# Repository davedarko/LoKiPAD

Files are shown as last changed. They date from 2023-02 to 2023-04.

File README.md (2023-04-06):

# LoKiPAD
A low cost adafruit [macropad](https://learn.adafruit.com/adafruit-macropad-rp2040/) clone with integrated todbot [MacroPadSynthPlug!](https://github.com/todbot/macropadsynthplug) Partslist is kept minimal and some things like the SD-card adapter, debug LED and speaker were dropped. Generic 12mm SMD buttons, 3535 WS2812B LEDs, an OLED module and a Raspberry PI Pico keep the price low. Check the ibom file for more info on the resistor and capacitor values. There's a small hack necessary so you don't have to remove the PCB from the case to push the BOOTSEL button - connect the pad with a jumper wire to a pin of the pico bootsel button.

## Code
Chose the Adafruit MacroPad RP2040 to compile the Arduino examples from todbot, so the SPI pins for the display are setup correctly. You also have to (re)define some pins to make the oled display and the LEDs work. There might be an issue with the encoder - if it feels backwards, just swap the PIN_ROTA and PIN_ROTB definition.

Since this is hardware to run todbots code, there's no code of my own to find here.

```c
#define PIN_NEOPIXEL 19
#define PIN_ROTA 18
#define PIN_ROTB 17
#define OLED_DC  14
#define OLED_RST 15
#define OLED_CS  22
```
## code of other people
This [MIDI controller code](https://gist.github.com/codeandmake/a2a5672fd49b748823cb352ba72d804a) by @codeandmake works great too, once you've changed the pin definition. 
---

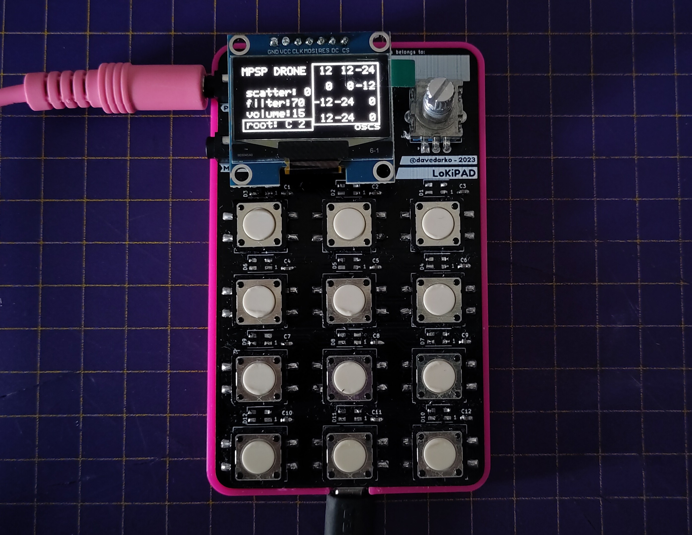
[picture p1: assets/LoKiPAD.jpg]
Picture of a 12 button macropad with an OLED and a encoder knob


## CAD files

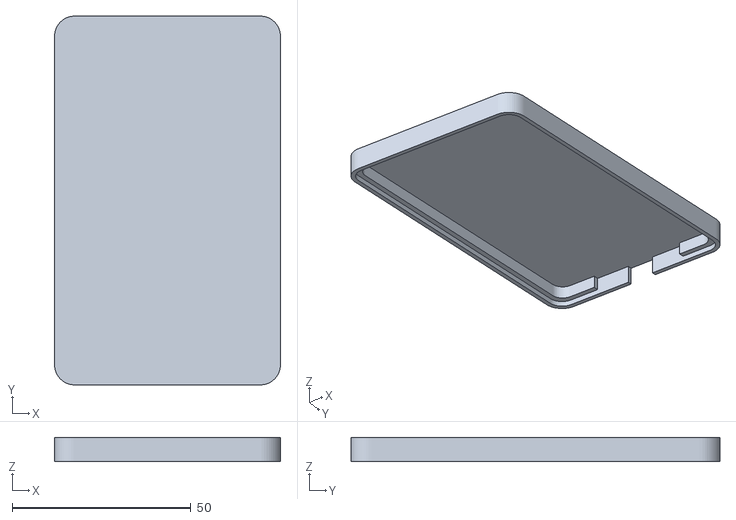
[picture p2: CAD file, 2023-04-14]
Case/LoKiPADcase.stl
63.3 x 103.3 x 6.75

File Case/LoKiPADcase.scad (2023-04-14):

use <rounded_box.scad>

$fn=50;

w=60;
d=100;
h=1.6;
r=4;

o=.3;
t=0.45*3;
th=7;
i=2.54;

screwHoles = false;
difference() {
	
	union () {
		
		rd = 2.5;
		if (screwHoles) {
			translate([-w/2+i,d/2-i,h]) cylinder(th-h-h+t, rd, rd);	
			translate([+w/2-i,d/2-i,h]) cylinder(th-h-h+t, rd, rd);
		}

		difference() {
		
		
			rounded_box(o+o+w+t+t,o+o+d+t+t,th-h+t,r+o+t);
			

			// first stage pcb rim
			translate([0,0,-1])
			rounded_box(w+o+o,d+o+o,h+1,r+o);
			
			// second stage holding corner
			translate([0,0,-1])
			rounded_box(w-t-t,d-t-t,th-h+1,r-o);

		 // color("black") rounded_box(w,d,h,r);
		
		}
	}
	
	if(screwHoles) {
		translate([-w/2+i,d/2-i,0]) cylinder(th-t, 1, 1);
		translate([+w/2-i,d/2-i,0]) cylinder(th-t, 1, 1);
	}
	
	usbSocket();



}

if($preview) {
	color("black", 0.5)
	rounded_box(w,d,h,r);
}

if($preview) usbSocket();

module usbSocket() {
	usb = 9;
	color("red", 0.2)
	translate([-usb/2,d/2-usb/2,-usb+th-h])
	cube(usb);
	
	usb2 = 32;
	color("red", 0.2)
	translate([-usb2/2,d/2-usb2+o,-usb2+th-h])
	cube(usb2);
	
}

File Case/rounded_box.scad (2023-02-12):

module rounded_box(w,d,h,r)
{
	union(){
		translate([-w/2+r, -d/2+r, 0]) cylinder(h, r, r);
		translate([-w/2+r, d/2-r, 0]) cylinder(h, r, r);
		translate([w/2-r, -d/2+r, 0]) cylinder(h, r, r);
		translate([w/2-r, d/2-r, 0]) cylinder(h, r, r);
		
		translate([-w/2+r, -d/2, 0]) cube([w-r*2,d,h]);
		translate([-w/2, -d/2+r, 0]) cube([w,d-r*2,h]);
	}
}

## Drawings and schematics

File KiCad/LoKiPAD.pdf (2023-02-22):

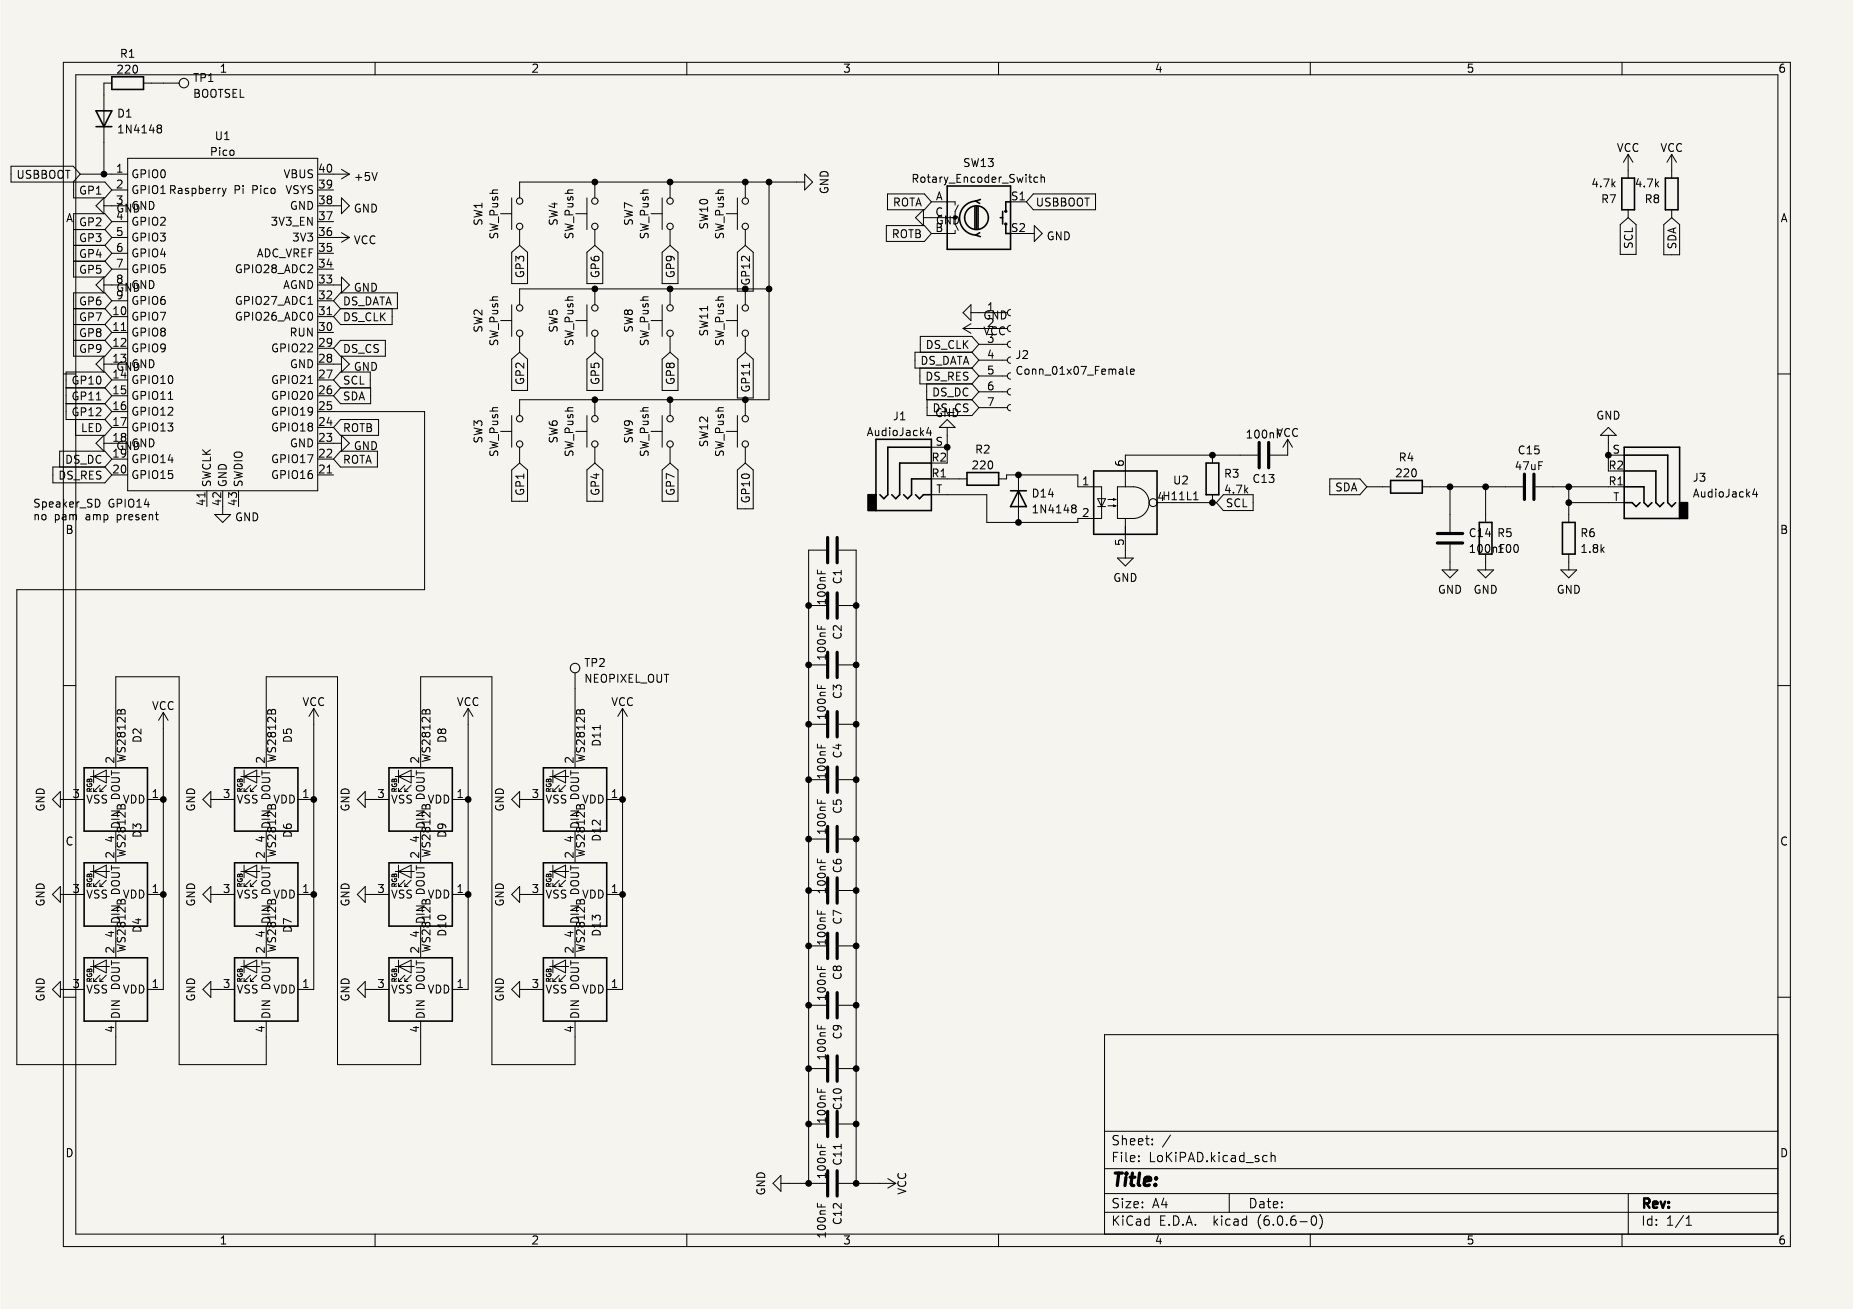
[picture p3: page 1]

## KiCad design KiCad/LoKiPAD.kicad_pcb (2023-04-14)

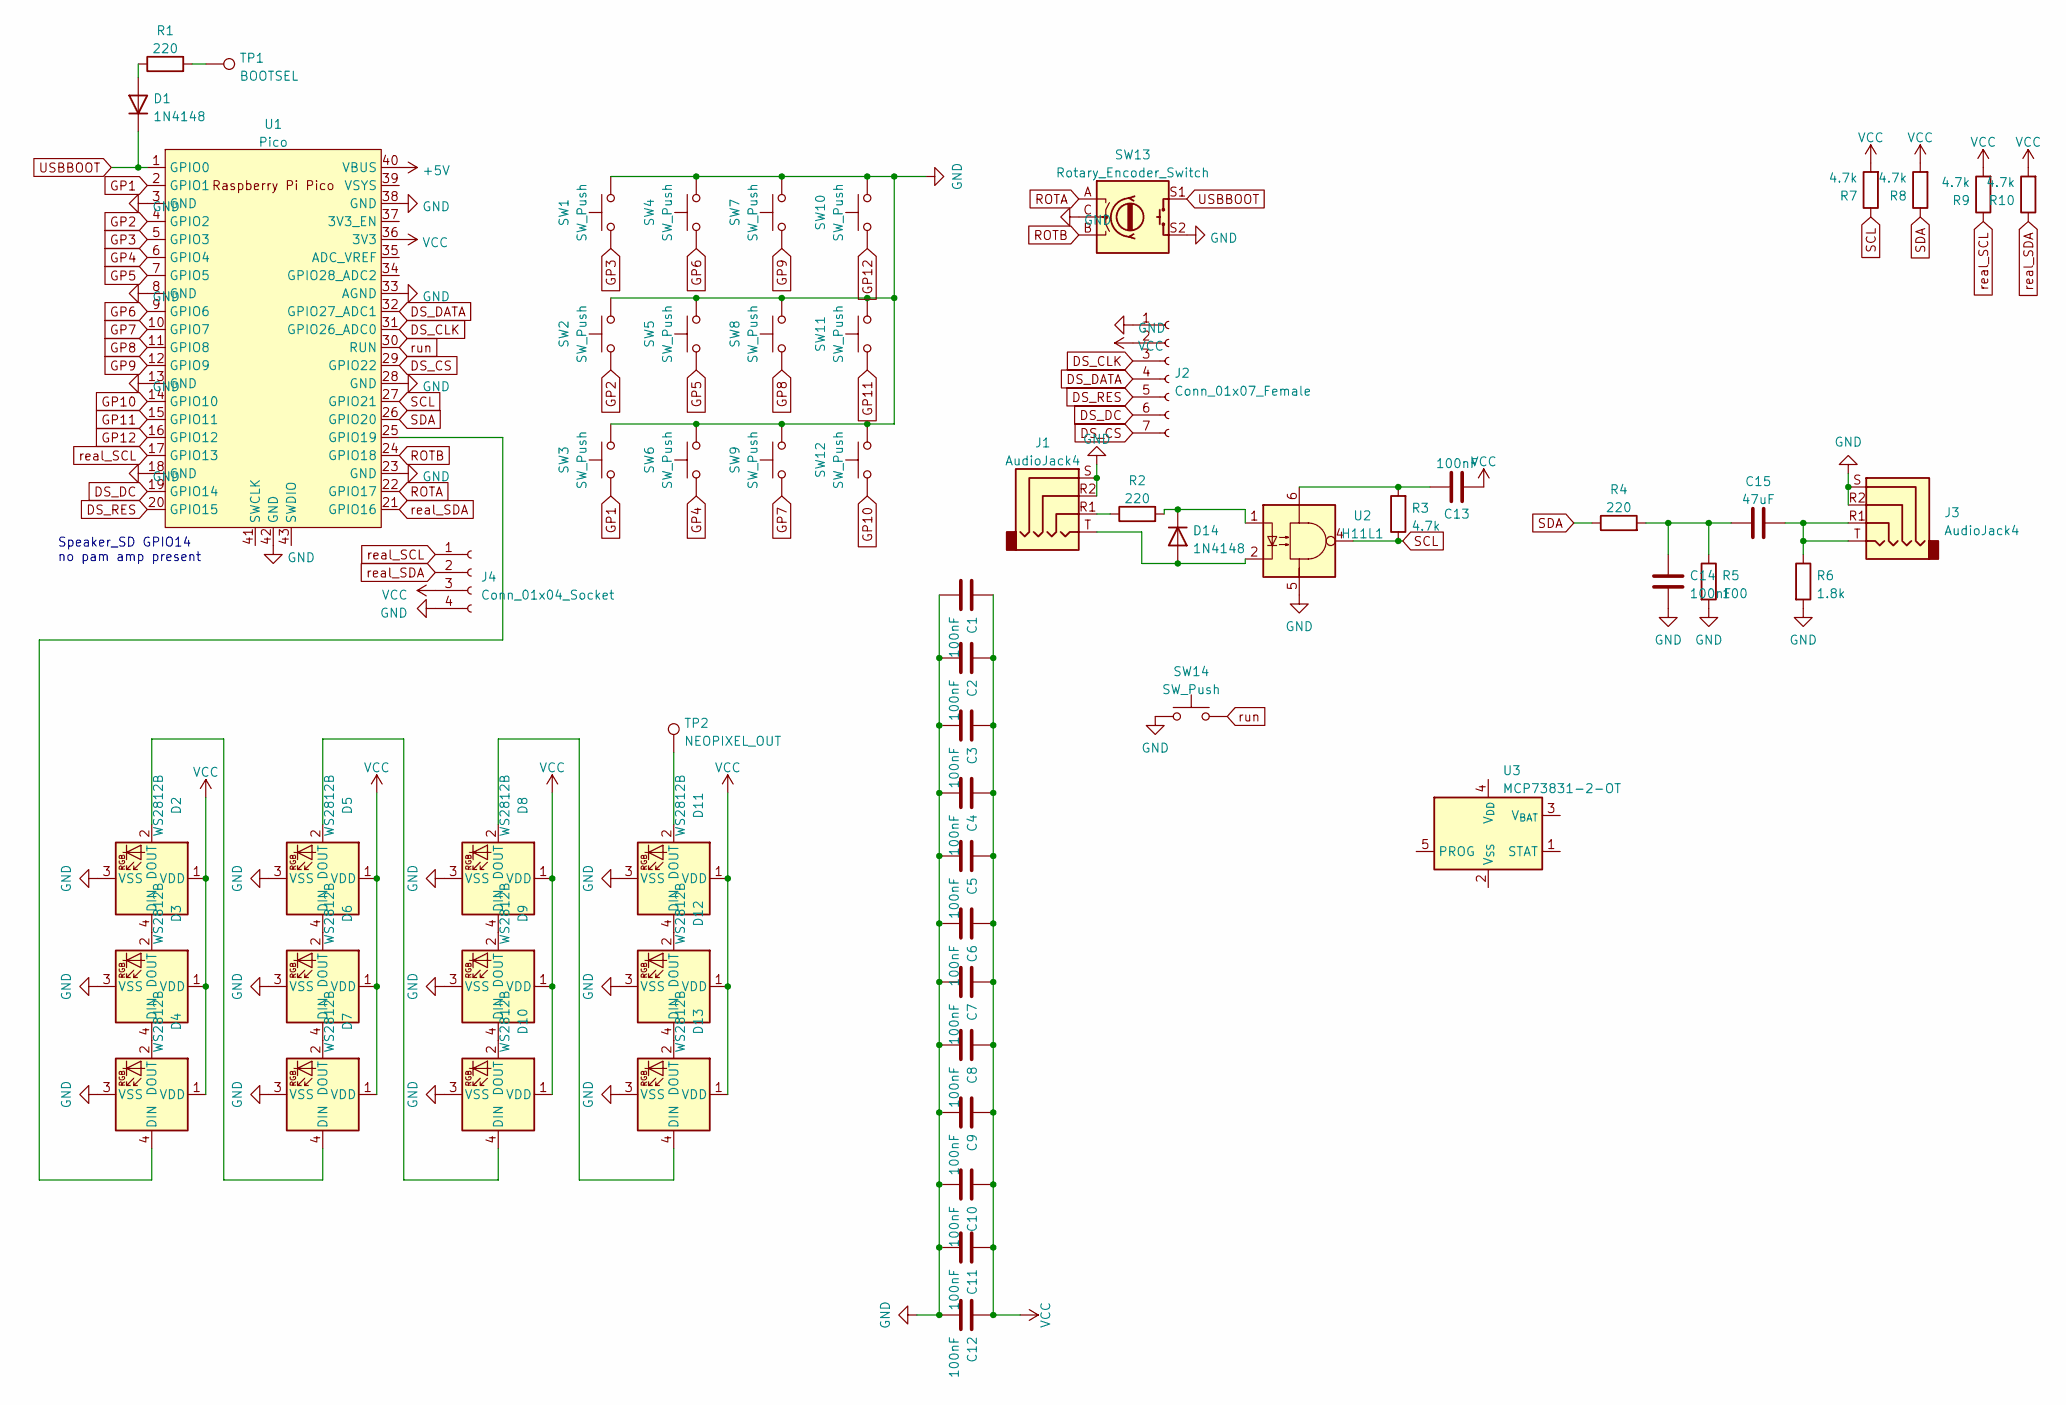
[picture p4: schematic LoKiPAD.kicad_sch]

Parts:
C1, C2, C3, C4, C5, C6, C7, C8, C9, C10, C11, C12, C13, C14: 100nF; C_0603_1608Metric_Pad1.08x0.95mm_HandSolder
C15: 47uF; C_0603_1608Metric_Pad1.08x0.95mm_HandSolder
D1, D14: 1N4148; D_0805_2012Metric_Pad1.15x1.40mm_HandSolder
D2, D3, D4, D5, D6, D7, D8, D9, D10, D11, D12, D13: WS2812B; LED_SK6812MINI_PLCC4_3.5x3.5mm_P1.75mm
J1, J3: AudioJack4; Jack_3.5mm_PJ320D_Horizontal
J2: Conn_01x07_Female; PinHeader_1x07_P2.54mm_Vertical
J4: Conn_01x04_Socket; JST_SH_BM04B-SRSS-TB_1x04-1MP_P1.00mm_Vertical
R1, R2, R4: 220; R_0603_1608Metric_Pad0.98x0.95mm_HandSolder
R3, R7, R8, R9, R10: 4.7k; R_0603_1608Metric_Pad0.98x0.95mm_HandSolder
R5: 100; R_0603_1608Metric_Pad0.98x0.95mm_HandSolder
R6: 1.8k; R_0603_1608Metric_Pad0.98x0.95mm_HandSolder
SW1, SW2, SW3, SW4, SW5, SW6, SW7, SW8, SW9, SW10, SW11, SW12: SW_Push; SW_PUSH-12mm-SMD
SW13: Rotary_Encoder_Switch; RotaryEncoder_Alps_EC11E-Switch_Vertical_H20mm_CircularMoun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
SW14: SW_Push; SW_Push_1P1T_NO_CK_KMR2
TP1: BOOTSEL; TestPoint_Pad_D1.5mm
TP2: NEOPIXEL_OUT; TestPoint_Pad_D1.5mm
U1: Pico; RPi_Pico_SMD
U2: H11L1; DIP-6_W8.89mm_SMDSocket_LongPads
U3: MCP73831-2-OT; SOT-23-5

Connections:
+5V: U1.40 (VBUS)
DS_CLK: J2.3, U1.31 (GPIO26_ADC0)
DS_CS: J2.7, U1.29 (GPIO22)
DS_DATA: J2.4, U1.32 (GPIO27_ADC1)
DS_DC: J2.6, U1.19 (GPIO14)
DS_RES: J2.5, U1.20 (GPIO15)
GND: C1.2, C2.2, C3.2, C4.2, C5.2, C6.2, C7.2, C8.2, C9.2, C10.2, C11.2, C12.2, C14.2, D2.3 (VSS), D3.3 (VSS), D4.3 (VSS), D5.3 (VSS), D6.3 (VSS), D7.3 (VSS), D8.3 (VSS), D9.3 (VSS), D10.3 (VSS), D11.3 (VSS), D12.3 (VSS), D13.3 (VSS), J1.R2, J1.S, J2.1, J3.R2, J3.S, J4.4, R5.2, R6.2, SW1.2, SW2.2, SW3.2, SW4.2, SW5.2, SW6.2, SW7.2, SW8.2, SW9.2, SW10.2, SW11.2, SW12.2, SW13.C, SW13.S2, SW14.1, U1.3 (GND), U1.8 (GND), U1.13 (GND), U1.18 (GND), U1.23 (GND), U1.28 (GND), U1.33 (AGND), U1.38 (GND), U1.42 (GND), U2.5
GP1: SW3.1, U1.2 (GPIO1)
GP2: SW2.1, U1.4 (GPIO2)
GP3: SW1.1, U1.5 (GPIO3)
GP4: SW6.1, U1.6 (GPIO4)
GP5: SW5.1, U1.7 (GPIO5)
GP6: SW4.1, U1.9 (GPIO6)
GP7: SW9.1, U1.10 (GPIO7)
GP8: SW8.1, U1.11 (GPIO8)
GP9: SW7.1, U1.12 (GPIO9)
GP10: SW12.1, U1.14 (GPIO10)
GP11: SW11.1, U1.15 (GPIO11)
GP12: SW10.1, U1.16 (GPIO12)
unnamed: C13.1, R3.2, U2.6
unnamed: C14.1, C15.1, R4.2, R5.1
unnamed: C15.2, J3.R1, J3.T, R6.1
unnamed: D1.2 (A), R1.1
unnamed: D2.4 (DIN), D3.2 (DOUT)
unnamed: D2.2 (DOUT), D7.4 (DIN)
unnamed: D3.4 (DIN), D4.2 (DOUT)
unnamed: D4.4 (DIN), U1.25 (GPIO19)
unnamed: D5.4 (DIN), D6.2 (DOUT)
unnamed: D6.4 (DIN), D7.2 (DOUT)
unnamed: D8.4 (DIN), D9.2 (DOUT)
unnamed: D5.2 (DOUT), D10.4 (DIN)
unnamed: D9.4 (DIN), D10.2 (DOUT)
unnamed: D11.4 (DIN), D12.2 (DOUT)
unnamed: D11.2 (DOUT), TP2.1
unnamed: D12.4 (DIN), D13.2 (DOUT)
unnamed: D8.2 (DOUT), D13.4 (DIN)
unnamed: D14.2 (A), J1.T, U2.2
unnamed: D14.1 (K), R2.2, U2.1
unnamed: J1.R1, R2.1
unnamed: R1.2, TP1.1
ROTA: SW13.A, U1.22 (GPIO17)
ROTB: SW13.B, U1.24 (GPIO18)
SCL: R3.1, R7.1, U1.27 (GPIO21), U2.4
SDA: R4.1, R8.1, U1.26 (GPIO20)
USBBOOT: D1.1 (K), SW13.S1, U1.1 (GPIO0)
VCC: C1.1, C2.1, C3.1, C4.1, C5.1, C6.1, C7.1, C8.1, C9.1, C10.1, C11.1, C12.1, C13.2, D2.1 (VDD), D3.1 (VDD), D4.1 (VDD), D5.1 (VDD), D6.1 (VDD), D7.1 (VDD), D8.1 (VDD), D9.1 (VDD), D10.1 (VDD), D11.1 (VDD), D12.1 (VDD), D13.1 (VDD), J2.2, J4.3, R7.2, R8.2, R9.2, R10.2, U1.36 (3V3)
real_SCL: J4.1, R9.1, U1.17 (GPIO13)
real_SDA: J4.2, R10.1, U1.21 (GPIO16)
run: SW14.2, U1.30 (RUN)

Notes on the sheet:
Speaker_SD GPIO14 no pam amp present

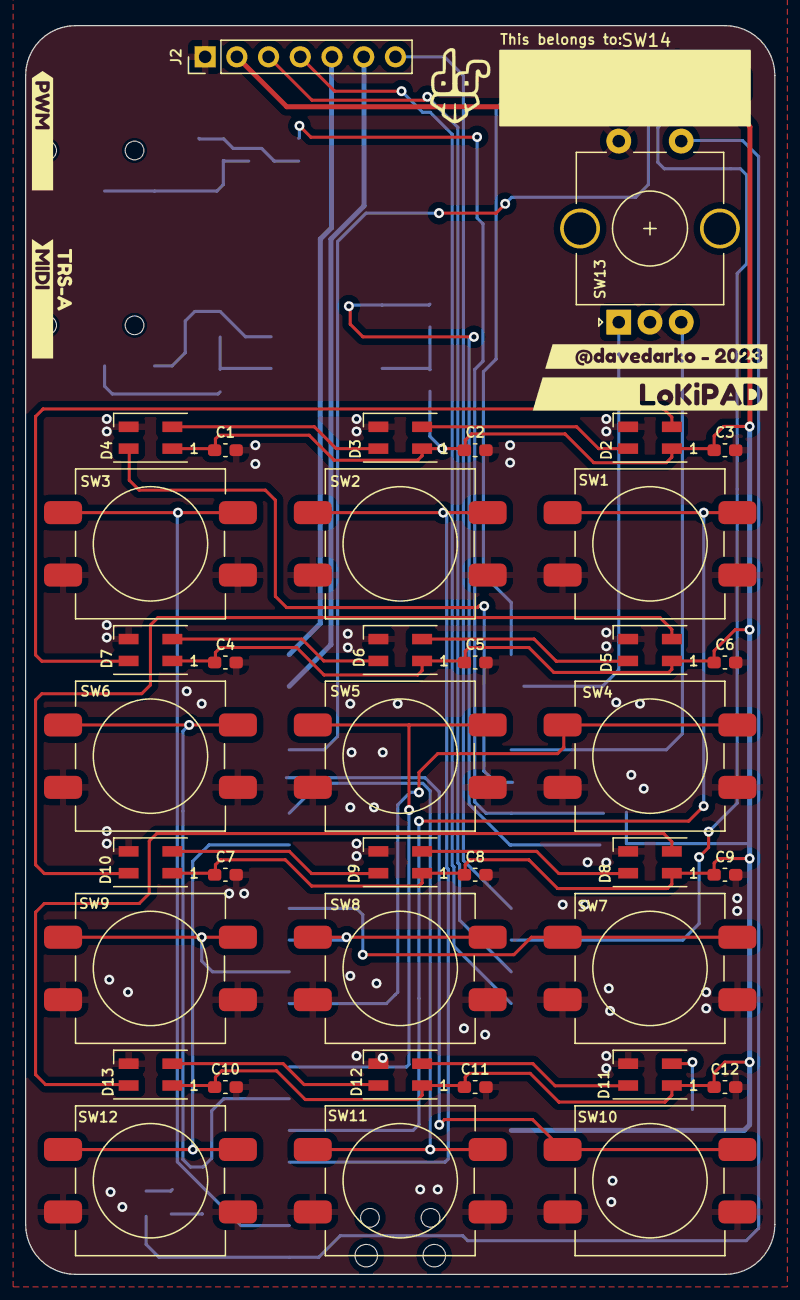
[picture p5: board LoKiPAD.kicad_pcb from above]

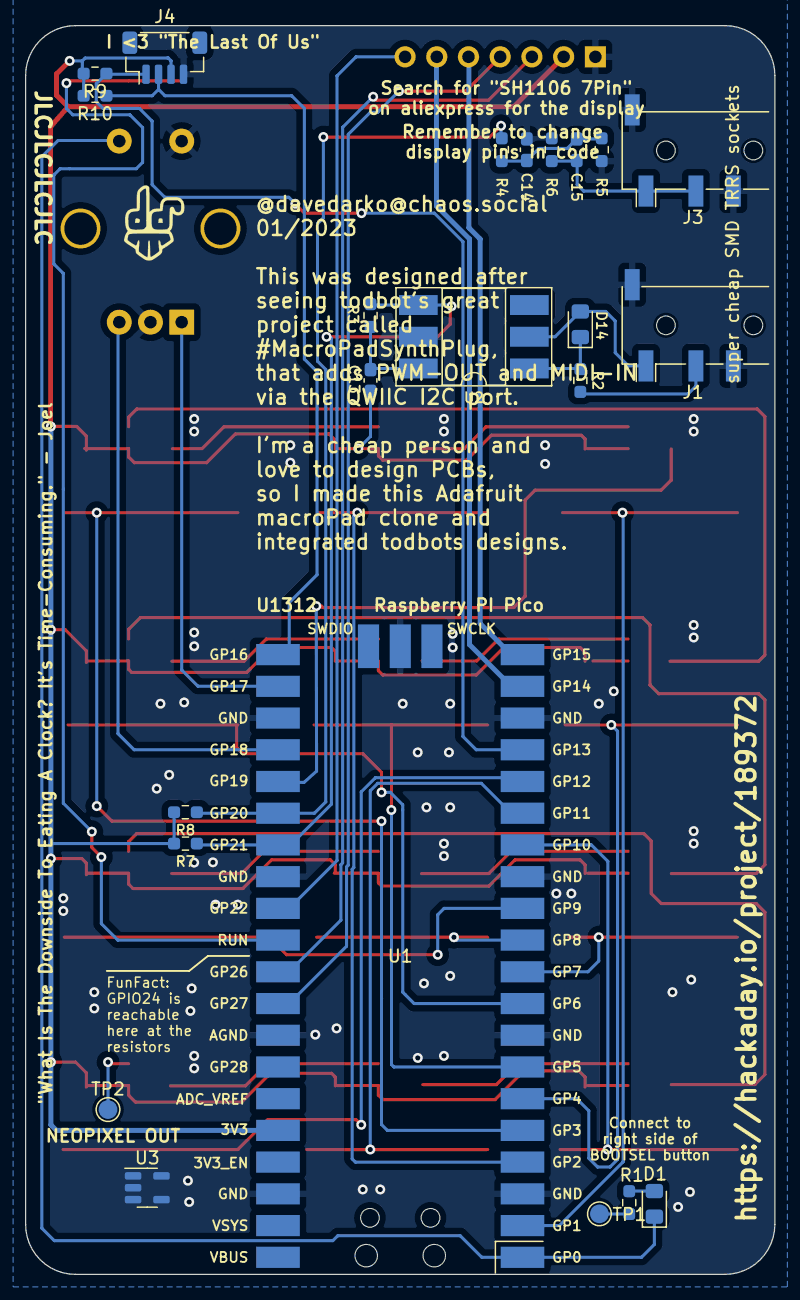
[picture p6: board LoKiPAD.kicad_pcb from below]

Board: 2 copper layers, 60.0 x 100.0 mm, 69 parts (24 on the bottom side), 48 nets.

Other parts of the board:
Ref**: Val**; davedarko_logo_silk_outline
Ref**#2: Val**; davedarko_logo_silk_outline
kibuzzard-63D6CFE9: G***; kibuzzard-63D6CFE9
kibuzzard-63D676B5: G***; kibuzzard-63D676B5
kibuzzard-63D67702: G***; kibuzzard-63D67702
kibuzzard-63D67711: G***; kibuzzard-63D67711
kibuzzard-63E7EF8E: G***; kibuzzard-63E7EF8E

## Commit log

2023-02-12 pcbs design files and case
    [LoKiPAD.kicad_pcb, LoKiPAD.kicad_sch, LoKiPADcase.scad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]
2023-02-12 added rounded box file
    [rounded_box.scad]
2023-02-22 schematics pdf
2023-04-14 bigger cutout for pico
    [LoKiPADcase.scad, LoKiPADcase.stl]
2023-04-14 more parts moved to back, kicad7
    [LoKiPAD.kicad_pcb, LoKiPAD.kicad_sch]
